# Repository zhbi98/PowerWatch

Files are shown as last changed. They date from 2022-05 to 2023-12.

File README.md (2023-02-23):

# PowerWatch 迷你 USB 电源功率计

## 1. 项目简介

PowerWatch 是我设计的一个 Mini-USB 电源功率计，设计包含外观结构，电路 PCB，程序固件。

PowerWatch 在硬件设计上支持同时采样被测电源的电压，电流及功率等参数，同时通过软件的形式实现了电能实时监测功能。

电能实时监测功能可以方便的知道被监测电源所输出的电能。 比如通过 PowerWatch 可以知道充电宝为手机充电时，充电宝流入手机的电能为多少 mAh。

而其中 mAh 表明的是电能单位，例如以 $x$ mA 电流持续输出 $1$ h 时间，则输出的电能为 $x$ mAh。

## 2. 硬件介绍

**(1)** 微控制器：采用国产兆易 GD32F103RCT6，芯片主频 96MHz 最高可达 108MHz，64P 引脚，RAM 空间 64KB，ROM 空间 256KB，支持 USB 通信。

**(2)** 屏幕：驱动芯片 ST7789V3，材质 IPS，采用 8 位并行 8080 通信接口，分辨率 320x170。

**(3)** Flash 芯片：GD25Q64 64MBit 即 8MByte。

**(4)** 电压电流采样芯片：采用德州仪器 TI 的 INA226AIDGSR 芯片。 

**(5)** 外壳模型：3D 打印，材料使用尼龙或工程塑料 。

## 3. 目录说明

### 3.1 Firmware 目录

该目录包含 PowerWatch 的所有功能源码实现，芯片驱动库，以及 Keil 编译工程所在目录，现在来简单介绍一下。

`mdk5/` 目录即为 MDK-ARM（即 Keil5 集成开发环境） 的工程文件。

`test/` 目录包含所有功能实现源码，以及需要用到的芯片驱动库，图形界面库 LVGL。

程序主要包含以下内容：

**(1)** GD32f103 的 USB Device 设备驱动，USB 驱动使用的设备描述符是 CDC 虚拟串口，使用 USB 接口可以用于和上位机进行数据通讯。

**(2)** ST7789V3 屏幕芯片驱动。

**(3)** 电压电流采样芯片驱动。

**(4)** 移植好的 LVGL8.2.0 的 UI 绘图库，这个 UI 库可以实现美观的图形界面，使用 LVGL 后就不需要我们自己控制屏幕逐像素的绘制图形来实现 UI 了。

注意：如果需要编译此工程需要安装 keil5 集成开发环境，以及在 keil5 中安装 GD32F10 系列的芯片描述包, 安装好后点击本项目工程文件夹下的工程文件启动 keil 直接编译即可。

GD32F10 芯片描述包可以到兆易官方网站下载，找到 **GD32F1x0 AddOn** 压缩包，芯片描述包就在该压缩包下，下载地址：[点击这里](https://www.gd32mcu.com/cn/download/7?kw=GD32F1)。

---

power_watch_firmware_v1.0.hex：为 PowerWatch 源码的编译后的固件，如果使用编译固件，需要使芯片进入 BOOT 模式，并使用 PCB 板上预留的串口来写入该固件。

### 3.2 Hardware 目录

PowerWatch 的 PCB 工程源文件，该文件夹下包含电路原理图，以及 PCB 制造文件（即 Gerber 文件），器件 BOM 单（用于 SMT 贴片），器件位置文件（用于 SMT 贴片）。

将 Gerber 文件压缩后到嘉立创网站下单即可将 PCB 打样出来，BOM 单和器件位置文件是嘉立创格式，PCB 打样后可以自行按照 BOM 单购买元器件手工焊接，或利用我提供的 BOM 单和器件坐标文件运用嘉立创的 SMT 贴片服务来贴片。

硬件 PCB 已经打样验证通过，想制作的小伙伴可以放心打样使用。

---

PCB 设计时原本的设想是使用 **STM32F103RCT6** 这颗芯片作为微控制器使用的，但是奈何 **STM32F103RCT6** 价格较高，所以最终芯片使用的是国产兆易的 **GD32F103RCT6** 系列芯片。

但是这对电路并不影响，因为 **GD32F103RCT6** 可以不需要任何改动而实现 PIN 对 PIN 的引脚以及外设兼容 **STM32F103RCT6** 芯片（即它们的每一根引脚和外设的功能是相同的）。

### 3.3 Image 目录

该目录是功率计制作实物效果图片展示，观看制作效果可以查看该目录下的实物照片。

### 3.4 Structure 目录

该目录存放功率计外壳模型文件 `.step` 格式，外壳模型包含壳体，按键帽，屏幕支架，上盖板，直接下载用于 3D 打印即可。

为了美观考虑盖板最好使用透明亚克力板进行制作，普通 3D 打印无法实现透明。

**(1)** 壳体 box_v2.0.step 建议采用黑色尼龙材材料 3D 打印。

**(2)** 屏幕支架 bracket_v2.0.step 建议采用透明树脂材料 3D 打印。

**(3)** 上盖板 panel_v2.0.step 建议采用亚克力或聚碳酸酯材料 CNC 加工。

**(4)** 按键帽 button1_v2.0.step，button2_v2.0.step，button3_v2.0.step，button4_v2.0.step 建议采用尼龙材料 3D 打印。

### 3.5 Docs 目录

用到的芯片配套的数据手册。

## 4. 外观设计

**最初的 V1.0 版本模型效果**

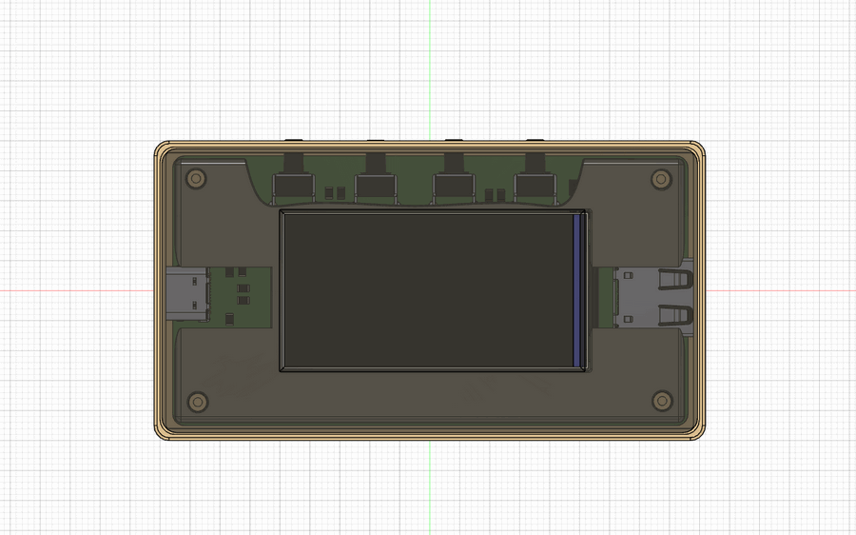
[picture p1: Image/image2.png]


**改进后 V2.0 版本模型效果**

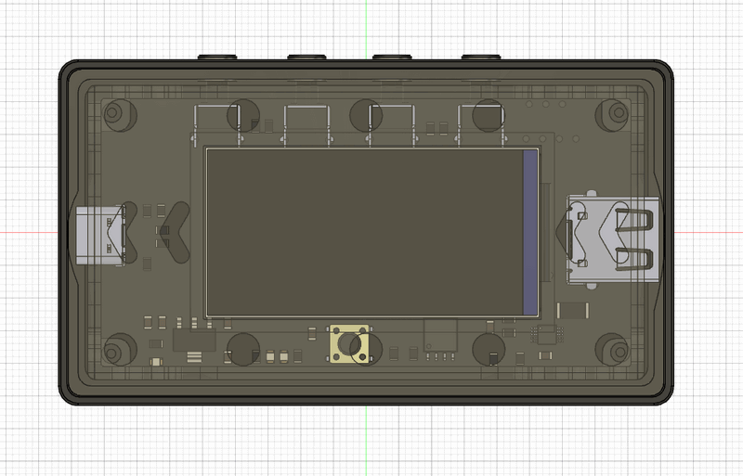
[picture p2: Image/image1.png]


## 5. 实物展示

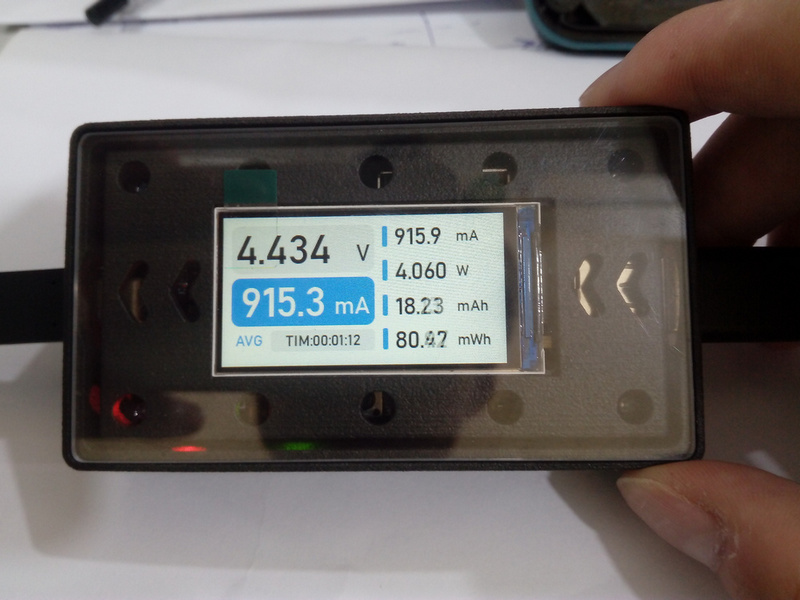
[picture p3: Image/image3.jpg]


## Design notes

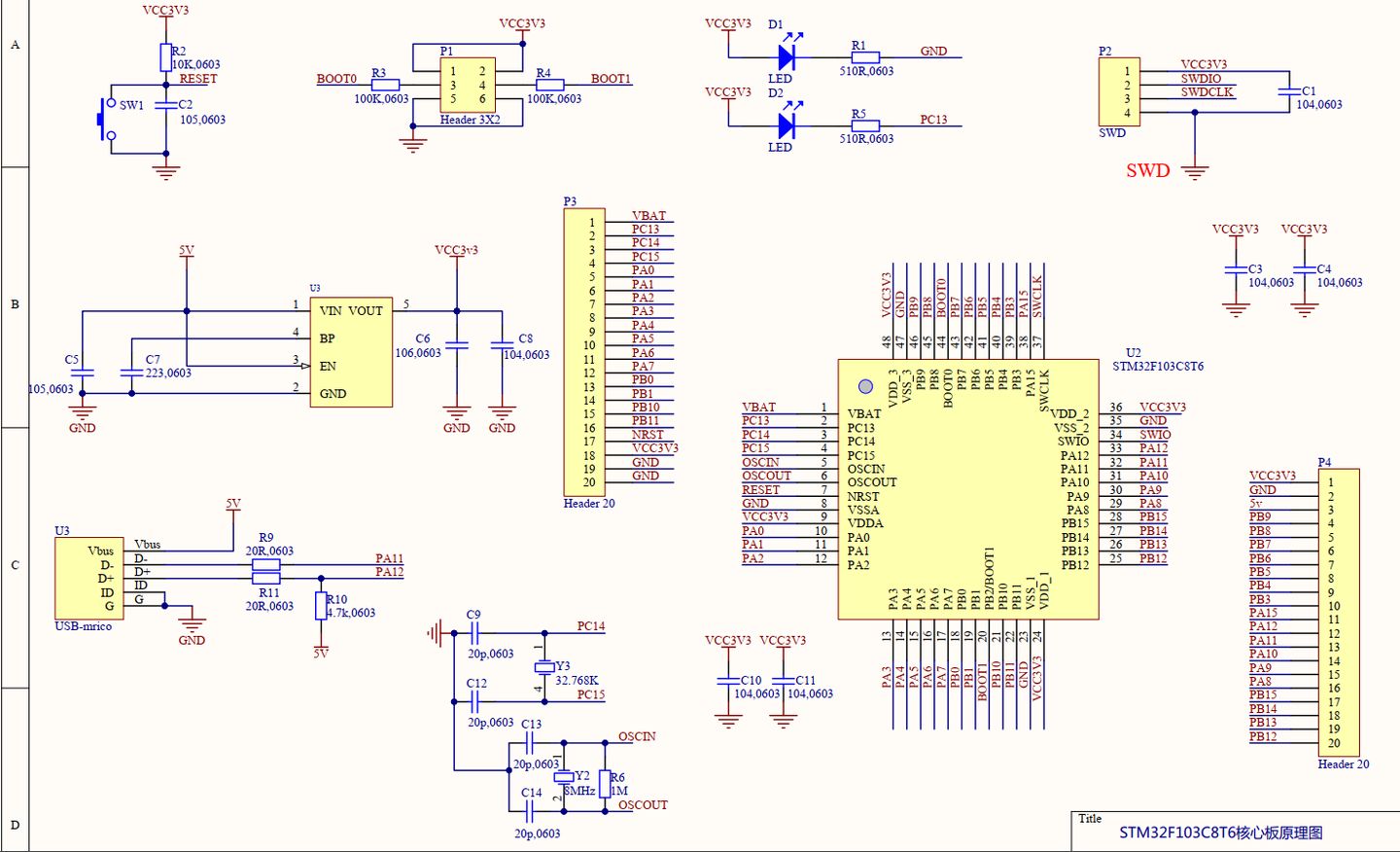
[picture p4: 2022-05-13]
Docs/STM32.jpg

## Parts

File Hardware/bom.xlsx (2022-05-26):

Comment型号 | Designator位号 | Footprint封装
22pF | C1,C4 | 0805
10uF | C2,C5 | 0805
0.1uF | C3,C6,C7,C8,C9,C10,C11,C12,C13 | 0805
17-21/R6C-AQ2R2B/3T | D1 | 0805
17-21SYGC/S530-E3/TR8 | D2 | 0805
17-21SYGC/S530-E3/TR8 | D3 | 0805
TYPE-C-31-M-12 | J3 | USB4105-GF-A
KH-FG0.5-H2.0-30PIN | J4 | Hirose_FH12-30S-0.5SH_1x30-1MP_P0.50mm_Horizontal
903-241B1011D10100 | J6 | USB1130-15-A_REVA
MMBT3906 | Q1 | SOT-23
220R | R1,R2,R3,R4,R14 | 0805
10M | R5 | 0805
10K | R6,R10,R22,R24 | 0805
0.5K | R7,R8 | 0805
1k | R9 | 0805
20R | R11, R12 | 0805
1K | R13 | 0805
100mR | R15 | 2010
5.1K | R16,R17,R18,R19,R20,R21 | 0805
100R | R23 | 0805
1-1825027-1 | S1,S2,S3,S4 | B3F-3100
1825910-6 | SW1 | B3F-1000
LM1117 | U1 | SOT-223
GD32F103RCT6 | U2 | LQFP-64_10x10mm_P0.5mm
INA226 | U3 | SOP50P490X110-10N
W25Q32JVSS | U4 | SOIC127P790X216-8N
49MD-8.00-20-10-10/A | Y1 | 49SMD

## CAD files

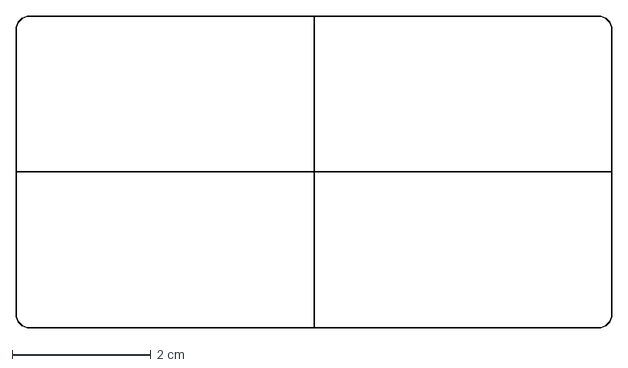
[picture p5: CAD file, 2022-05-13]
Hardware/edge_cuts.dxf
8.60 x 4.50 cm

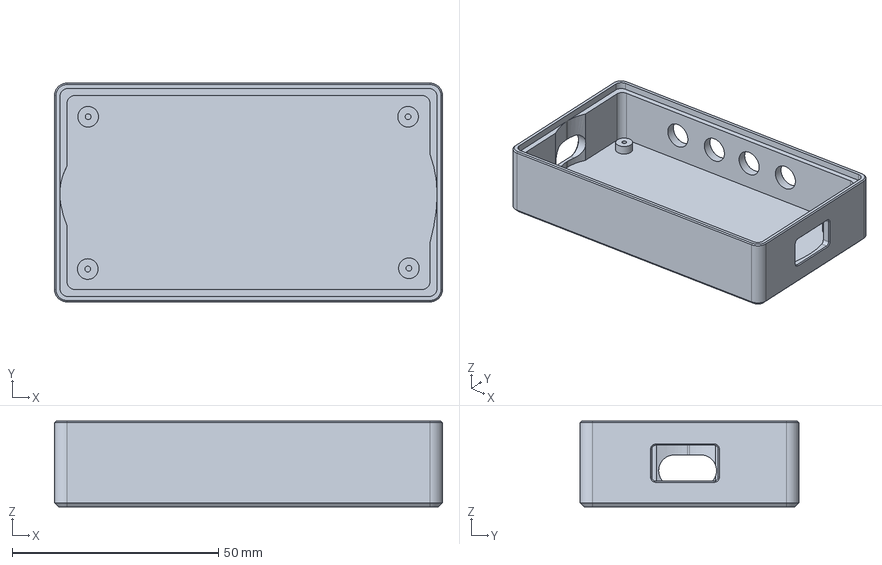
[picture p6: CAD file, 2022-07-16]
Structure/box_v2.0.step
94.0 x 53.0 x 20.8 mm

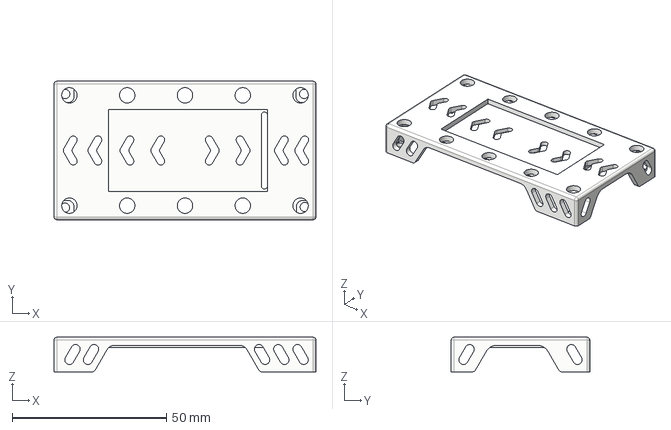
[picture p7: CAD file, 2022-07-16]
Structure/bracket_v2.0.step
85.0 x 45.0 x 11.3 mm

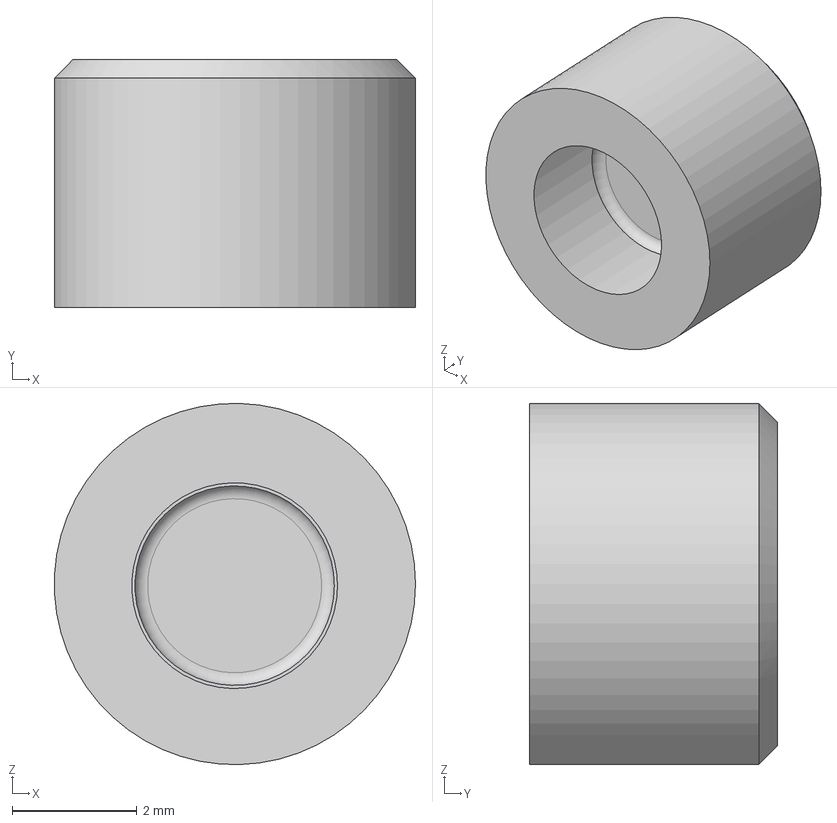
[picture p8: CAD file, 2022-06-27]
Structure/button2_v2.0.step
5.80 x 3.98 x 5.80 mm

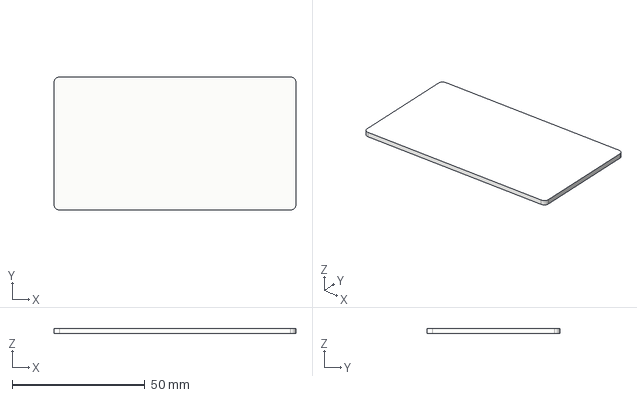
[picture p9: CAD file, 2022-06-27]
Structure/panel_v2.0.step
91.0 x 50.0 x 2.00 mm

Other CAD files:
Structure/button4_v2.0.step
Structure/button3_v2.0.step
Structure/button1_v2.0.step

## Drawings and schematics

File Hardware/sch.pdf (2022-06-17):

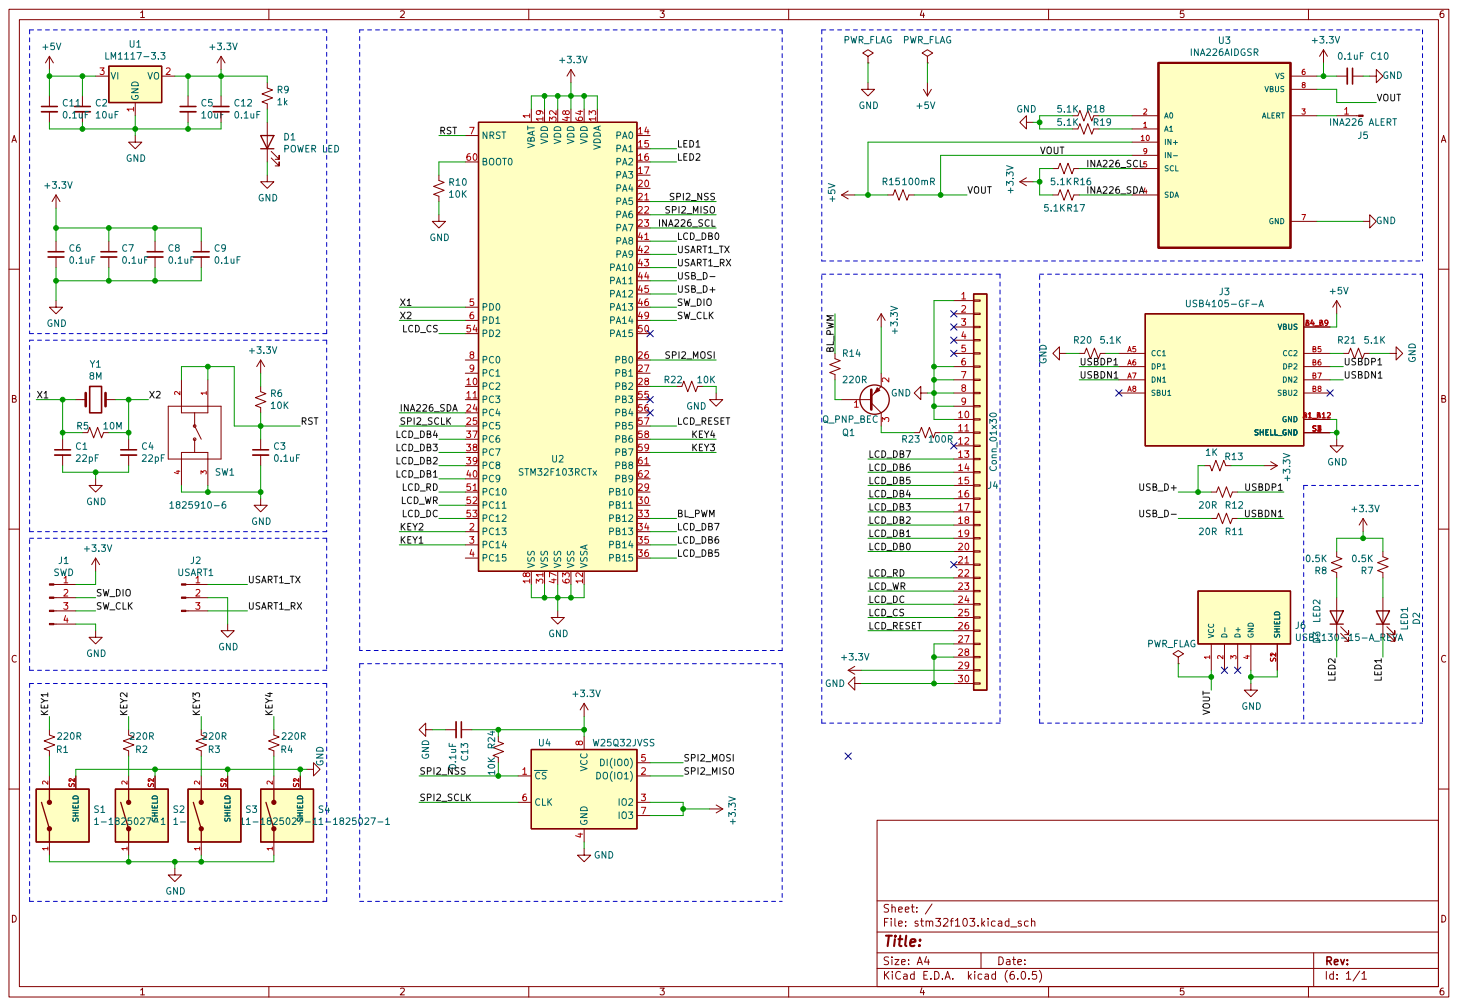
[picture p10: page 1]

1 PC2 10 PC3 11 VSSA 12 VDDA 13 PA0 14 PA1 15 PA2 16 PA3 17 VSS 18 VDD 19 PC13 2 PA4 20 PA5 21 PA6 22 PA7 23 PC4 24 PC5 25 PB0 26 PB1 27 PB2 28 PB10 29 PC14 3 PB11 30 VSS 31 VDD 32 PB12 33 PB13 34 PB14 35 PB15 36 PC6 37 PC7 38 PC8 39 PC15 4 PC9 40 PA8 41 PA9 42 PA10 43 PA11 44 PA12 45 PA13 46 VSS 47 VDD 48 PA14 49 PD0 5 PA15 50 PC10 51 PC11 52 PC12 53 PD2 54 PB3 55 PB4 56 PB5 57 PB6 58 PB7 59 PD1 6 BOOT0 60 PB8 61 PB9 62 VSS 63 VDD 64 NRST 7 PC0 8 PC1 9 U2 STM32F103RCTx R22 10K GND

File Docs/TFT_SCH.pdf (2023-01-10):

# 中景园电子1.9寸IPS LCD显示屏模块原理图

# 分辩率：170x320

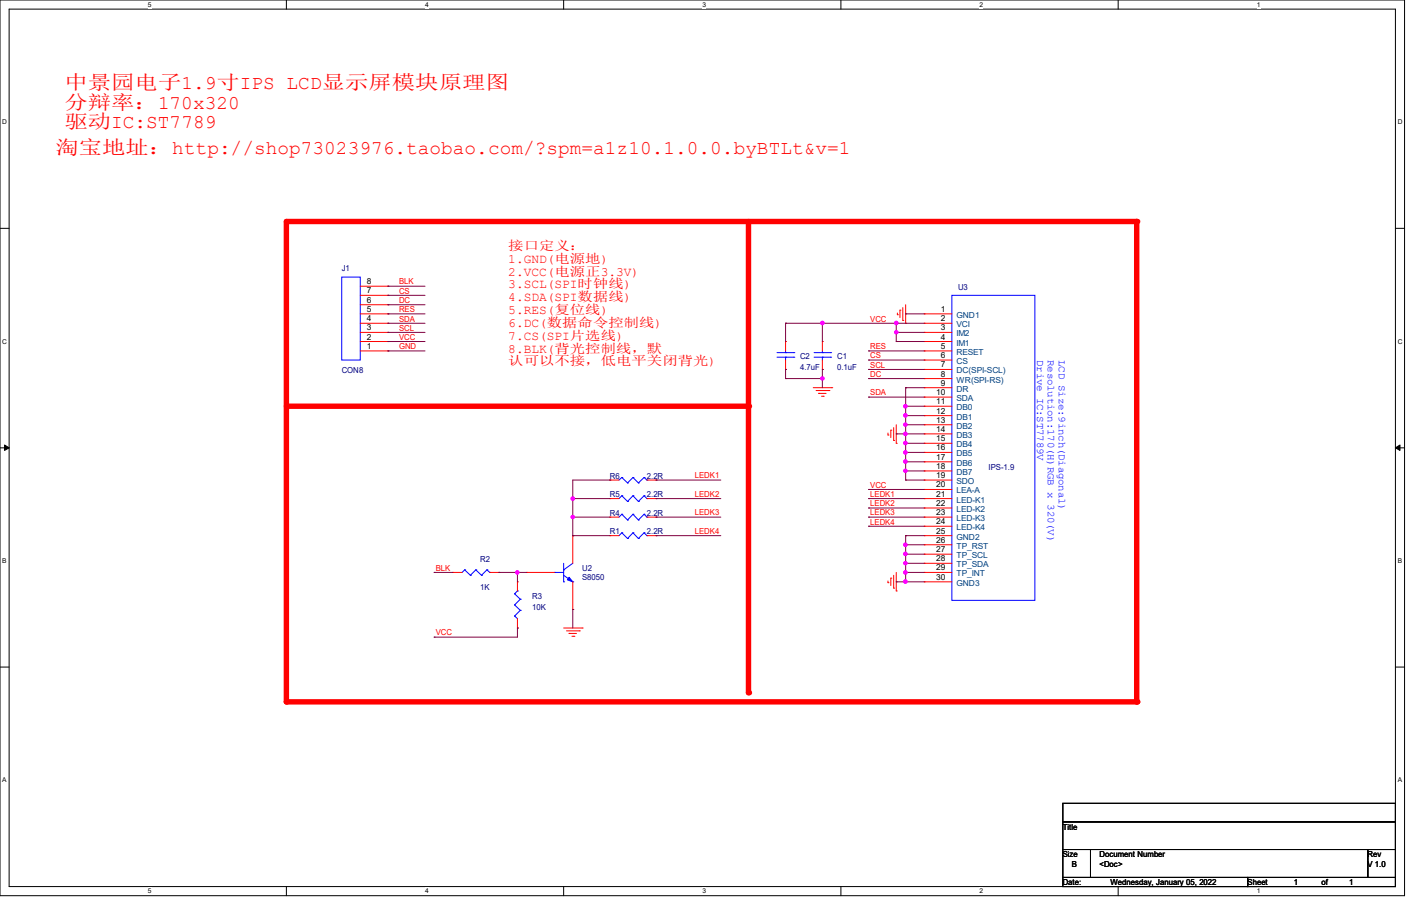
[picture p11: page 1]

驱动IC:ST7789
淘宝地址：http://shop73023976.taobao.com/?spm=a1z10.1.0.0.byBTLt&v=1

接口定义：
1.GND(电源地)
2.VCC(电源正3.3V)
3.SCL(SPI时钟线) 4.SDA(SPI数据线)

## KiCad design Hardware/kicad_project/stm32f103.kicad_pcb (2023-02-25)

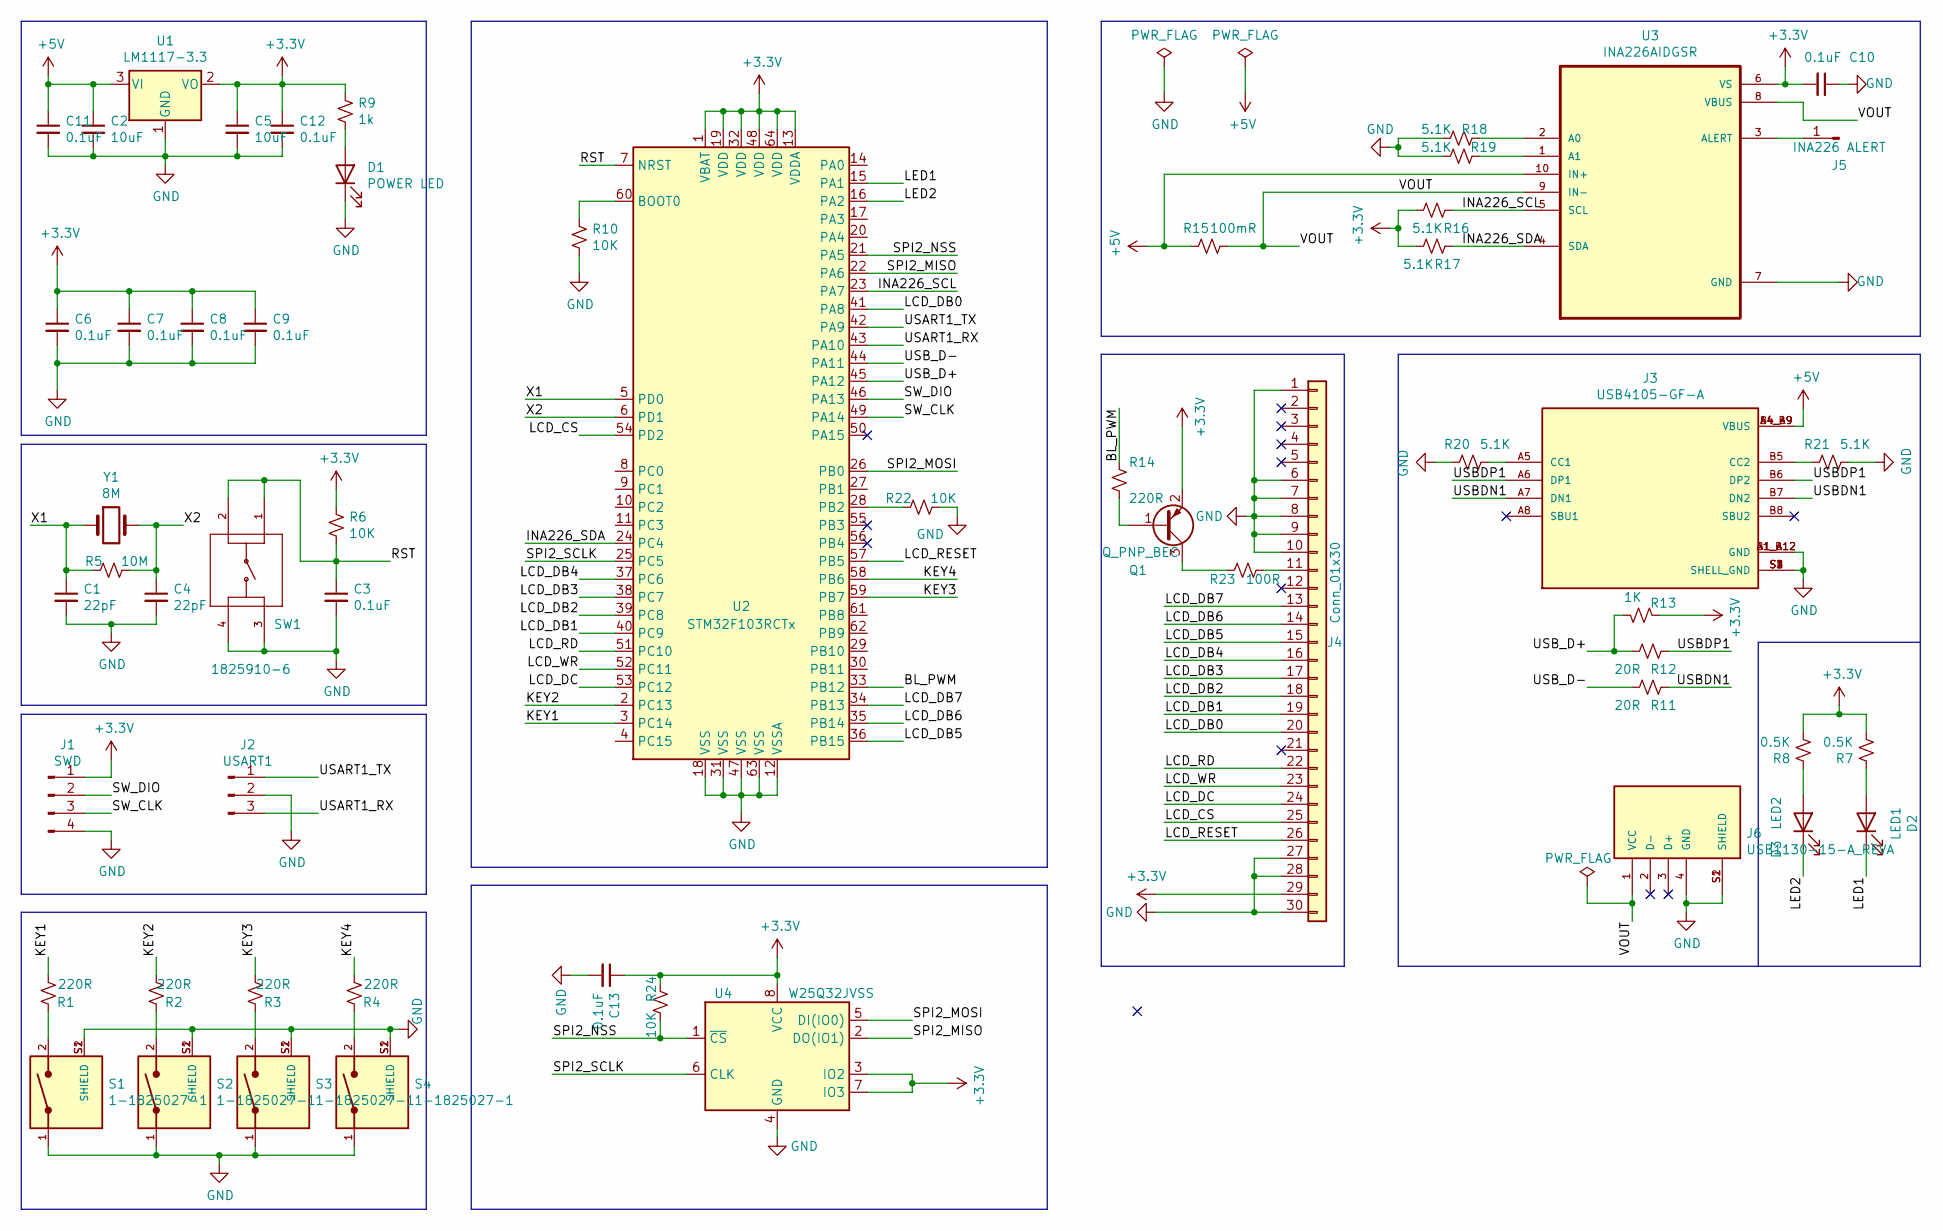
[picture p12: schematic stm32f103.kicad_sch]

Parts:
C1, C4: 22pF; C_0805_2012Metric
C2, C5: 10uF; C_0805_2012Metric
C3, C6, C7, C8, C9, C10, C11, C12, C13: 0.1uF; C_0805_2012Metric
D1: POWER LED; LED_0805_2012Metric
D2: LED1; LED_0805_2012Metric
D3: LED2; LED_0805_2012Metric
J1: SWD; PinSocket_1x04_P2.54mm_Vertical
J2: USART1; PinSocket_1x03_P2.54mm_Vertical
J3: USB4105-GF-A; USB-C-SMD_16P_USB4105-GF-A; PARTREV A3
J4: Conn_01x30; Hirose_FH12-30S-0.5SH_1x30-1MP_P0.50mm_Horizontal
J5: INA226 ALERT; PinSocket_1x01_P2.54mm_Vertical
J6: USB1130-15-A_REVA; USB-A-TH_4P_USB1130-15-A-REVA; PARTREV A
Q1: Q_PNP_BEC; SOT-23
R1, R2, R3, R4, R14: 220R; R_0805_2012Metric
R5: 10M; R_0805_2012Metric
R6, R10, R22, R24: 10K; R_0805_2012Metric
R7, R8: 0.5K; R_0805_2012Metric
R9: 1k; R_0805_2012Metric
R11, R12: 20R; R_0805_2012Metric
R13: 1K; R_0805_2012Metric
R15: 100mR; R_2010_5025Metric
R16, R17, R18, R19, R20, R21: 5.1K; R_0805_2012Metric
R23: 100R; R_0805_2012Metric
S1, S2, S3, S4: 1-1825027-1; KEY-TH_L6.0-W6.0-H_B3F-3100
SW1: 1825910-6; KEY-TH_L6.0-W6.0-V_B3F-1000
U1: LM1117-3.3; SOT-223
U2: STM32F103RCTx; LQFP-64_10x10mm_P0.5mm
U3: INA226AIDGSR; VSSOP-10_L2.9-W5.05-P0.5_INA226AIDGSR
U4: W25Q32JVSS; SOIC-8_L4.8-W5.8-P1.27_W25Q32JVSS
Y1: 8M; Crystal_SMD_HC49-SD

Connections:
+3V3: C5.1, C6.1, C7.1, C8.1, C9.1, C10.2, C12.1, C13.1, J1.1, J4.29, Q1.2 (E), R6.1, R7.2, R8.2, R9.1, R13.1, R16.1, R17.1, R24.2, U1.2 (VO), U2.1 (VBAT), U2.13 (VDDA), U2.19 (VDD), U2.32 (VDD), U2.48 (VDD), U2.64 (VDD), U3.6 (VS), U4.3 (IO2), U4.7 (IO3), U4.8 (VCC)
+5V: C2.1, C11.1, J3.A4_B9 (VBUS), J3.B4_A9 (VBUS), R15.2, U1.3 (VI), U3.10 (IN+)
/BL_PWM: R14.1, U2.33 (PB12)
/INA226_SCL: R16.2, U2.23 (PA7), U3.5 (SCL)
/INA226_SDA: R17.2, U2.24 (PC4), U3.4 (SDA)
/KEY1: R1.2, U2.3 (PC14)
/KEY2: R2.2, U2.2 (PC13)
/KEY3: R3.2, U2.59 (PB7)
/KEY4: R4.2, U2.58 (PB6)
/LCD_CS: J4.25, U2.54 (PD2)
/LCD_DB0: J4.20, U2.41 (PA8)
/LCD_DB1: J4.19, U2.40 (PC9)
/LCD_DB2: J4.18, U2.39 (PC8)
/LCD_DB3: J4.17, U2.38 (PC7)
/LCD_DB4: J4.16, U2.37 (PC6)
/LCD_DB5: J4.15, U2.36 (PB15)
/LCD_DB6: J4.14, U2.35 (PB14)
/LCD_DB7: J4.13, U2.34 (PB13)
/LCD_DC: J4.24, U2.53 (PC12)
/LCD_RD: J4.22, U2.51 (PC10)
/LCD_RESET: J4.26, U2.57 (PB5)
/LCD_WR: J4.23, U2.52 (PC11)
/LED1: D2.1 (K), U2.15 (PA1)
/LED2: D3.1 (K), U2.16 (PA2)
/RST: C3.1, R6.2, SW1.1, SW1.2, U2.7 (NRST)
/SPI2_MISO: U2.22 (PA6), U4.2 (DO(IO1))
/SPI2_MOSI: U2.26 (PB0), U4.5 (DI(IO0))
/SPI2_NSS: R24.1, U2.21 (PA5), U4.1 (~CS)
/SPI2_SCLK: U2.25 (PC5), U4.6 (CLK)
/SW_CLK: J1.3, U2.49 (PA14)
/SW_DIO: J1.2, U2.46 (PA13)
/USART1_RX: J2.3, U2.43 (PA10)
/USART1_TX: J2.1, U2.42 (PA9)
/USBDN1: J3.A7 (DN1), J3.B7 (DN2), R11.2
/USBDP1: J3.A6 (DP1), J3.B6 (DP2), R12.2
/USB_D+: R12.1, R13.2, U2.45 (PA12)
/USB_D-: R11.1, U2.44 (PA11)
/VOUT: J6.1 (VCC), R15.1, U3.8 (VBUS), U3.9 (IN-)
/X1: C1.1, R5.2, U2.5 (PD0), Y1.1
/X2: C4.1, R5.1, U2.6 (PD1), Y1.2
GND: C1.2, C2.2, C3.2, C4.2, C5.2, C6.2, C7.2, C8.2, C9.2, C10.1, C11.2, C12.2, C13.2, D1.1 (K), J1.4, J2.2, J3.A1_B12 (GND), J3.B1_A12 (GND), J3.S1 (SHELL_GND), J3.S2 (SHELL_GND), J3.S3 (SHELL_GND), J3.S4 (SHELL_GND), J4.1, J4.6, J4.7, J4.8, J4.9, J4.10, J4.27, J4.28, J4.30, J6.4 (GND), J6.S1 (SHIELD), J6.S2 (SHIELD), R10.2, R18.1, R19.1, R20.2, R21.1, R22.2, S1.1, S1.S1 (SHIELD), S1.S2 (SHIELD), S2.1, S2.S1 (SHIELD), S2.S2 (SHIELD), S3.1, S3.S1 (SHIELD), S3.S2 (SHIELD), S4.1, S4.S1 (SHIELD), S4.S2 (SHIELD), SW1.3, SW1.4, U1.1 (GND), U2.12 (VSSA), U2.18 (VSS), U2.31 (VSS), U2.47 (VSS), U2.63 (VSS), U3.7 (GND), U4.4 (GND)
unnamed: D1.2 (A), R9.2
unnamed: D2.2 (A), R7.1
unnamed: D3.2 (A), R8.1
unnamed: J3.A5 (CC1), R20.1
unnamed: J3.B5 (CC2), R21.2
unnamed: J4.11, R23.2
unnamed: J5.1, U3.3 (ALERT)
unnamed: Q1.1 (B), R14.2
unnamed: Q1.3 (C), R23.1
unnamed: R1.1, S1.2
unnamed: R2.1, S2.2
unnamed: R3.1, S3.2
unnamed: R4.1, S4.2
unnamed: R10.1, U2.60 (BOOT0)
unnamed: R18.2, U3.2 (A0)
unnamed: R19.2, U3.1 (A1)
unnamed: R22.1, U2.28 (PB2)

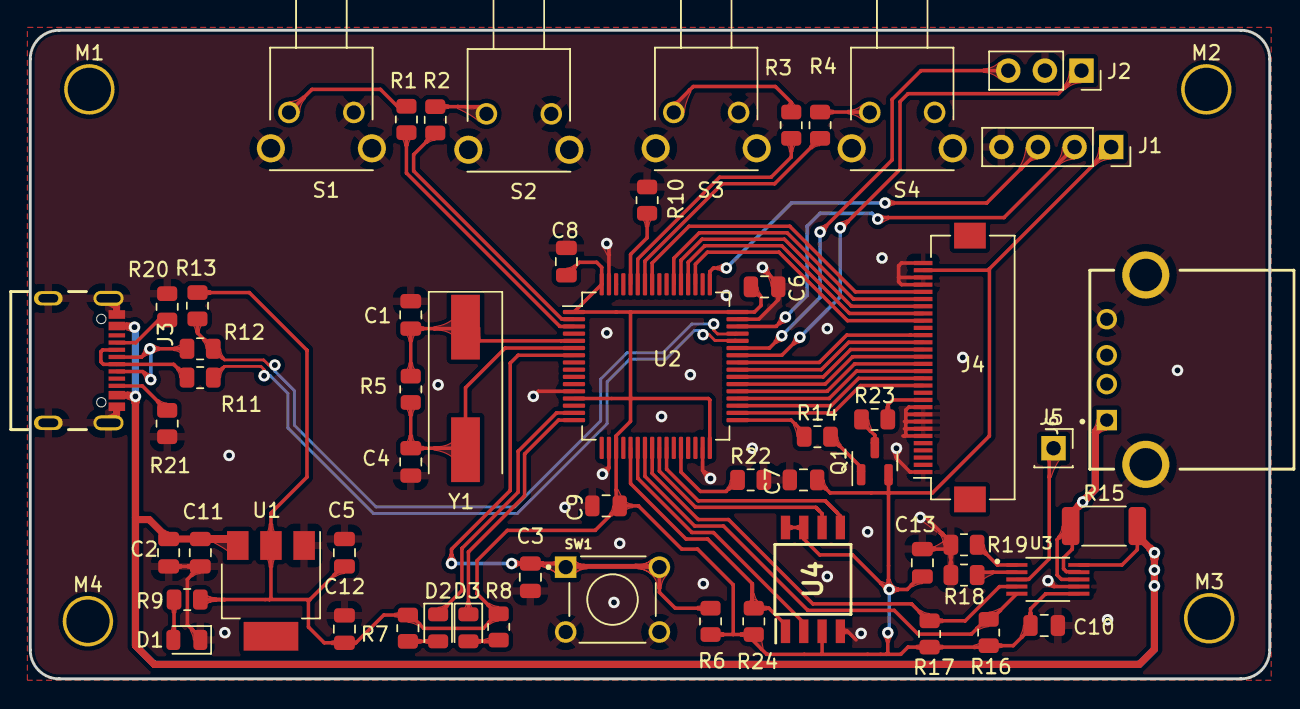
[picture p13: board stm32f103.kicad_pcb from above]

Board: 2 copper layers, 86.0 x 45.0 mm, 61 parts (0 on the bottom side), 58 nets.

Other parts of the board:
M1, M2, M3, M4: Mounting_Holes_3mm_THT

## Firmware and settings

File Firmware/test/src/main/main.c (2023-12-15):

/**
 * @file main.c
 *
 */

/*********************
 *      INCLUDES
 *********************/

#include "gd32f10x.h"

#include <stdint.h>
#include "led.h"
#include "key.h"
#include "time.h"
#include "log.h"
#include "usbd_cdc.h"
#include "st7789.h"
#include "ina226.h"
#include "gd25q64.h"
#include "temp.h"
#include "ina226.h"
#include "kalman.h"

#include "lvgl.h"
#include "nt_pm.h"
#include "nt_minitask.h"

#include "qflow.h"
#include "blight.h"

#include "dialplateview.h"
#include "dialplate.h"
#include "infosview.h"
#include "infos.h"
#include "recentview.h"
#include "recent.h"

#include "resource.h"

/**********************
 * GLOBAL FUNCTIONS
 **********************/

/**
  * 说明 : 初始化内核时钟(108M)
  * 参数 : 无
  * 返回 : 无
  */ 
void sys_clock_config(void)
{
    /** 使能外部晶振 */
    rcu_osci_on(RCU_HXTAL);
    /** 等待晶振稳定 */
    while (rcu_osci_stab_wait(RCU_HXTAL) != SUCCESS);

    /** 设置PREDV0 */
    rcu_predv0_config(RCU_PREDV0_DIV1);
    /** PLL设置 */
    rcu_pll_config(RCU_PLLSRC_HXTAL, RCU_PLL_MUL9);
    /** 使能PLL */
    rcu_osci_on(RCU_PLL_CK);
    /** 等待PLL稳定 */
    while (rcu_osci_stab_wait(RCU_HXTAL) != SUCCESS);

    /** 总线时钟配置 */
    rcu_ahb_clock_config(RCU_AHB_CKSYS_DIV1);
    rcu_apb1_clock_config(RCU_APB1_CKAHB_DIV2);
    rcu_apb2_clock_config(RCU_APB2_CKAHB_DIV1); 
    /** 系统时钟源选择 */
    rcu_system_clock_source_config(RCU_CKSYSSRC_PLL);
    while(rcu_system_clock_source_get() != RCU_SCSS_PLL);

    /** 更新SystemCoreClock全局变量 */
    SystemCoreClockUpdate();
}

/*
-----------------------------------------
    Timing 0.1s

    Prescaler = AHB Clock / Timing Clock
              = 84(MHz) / 50(KHz)
              = 84000000(hz) / 50000(hz)
              = 1680

    T = 1 / f
      = 1(s) / f(Hz)
      = 1000000(us) / 50000(hz)
      = 20(us/times)

    Period = Timing / T
           = 0.1(s) / 20(us/times)
           = 100000(us) / 20(us/times)
           = 5000(times)

-----------------------------------------
    Timing 0.5s
    
    Prescaler = AHB Clock / Timing Clock
              = 84(MHz) / 10(KHz)
              = 84000000(hz) / 10000(hz)
              = 8400

    T = 1 / f
      = 1(s) / f(Hz)
      = 1000000(us) / 10000(hz)
      = 100(us/times)

    Period = Timing / T
           = 0.5(s) / 100(us/times)
           = 500000(us) / 100(us/times)
           = 5000(times)
-----------------------------------------
*/

void _timer_init(uint32_t _prescaler, uint32_t _period)
{
    /**
     * TIMER configuration: generate PWM signals
     * with different duty cycles:
     * TIMERCLK = SystemCoreClock / 120 = 1MHz
     */
    timer_oc_parameter_struct timer_out_init;
    timer_parameter_struct time_init;

    rcu_periph_clock_enable(RCU_TIMER1);
    timer_deinit(TIMER1);

    time_init.prescaler         = _prescaler - 1;
    time_init.alignedmode       = TIMER_COUNTER_EDGE;
    time_init.counterdirection  = TIMER_COUNTER_UP;
    time_init.period            = _period;
    time_init.clockdivision     = TIMER_CKDIV_DIV1;
    time_init.repetitioncounter = 0;
    timer_init(TIMER1, &time_init);

#if 0
    CH0 config in pwm mode
    timer_out_init.outputstate  = TIMER_CCX_ENABLE;
    timer_out_init.outputnstate = TIMER_CCXN_DISABLE;
    timer_out_init.ocpolarity   = TIMER_OC_POLARITY_HIGH;
    timer_out_init.ocnpolarity  = TIMER_OCN_POLARITY_HIGH;
    timer_out_init.ocidlestate  = TIMER_OC_IDLE_STATE_LOW;
    timer_out_init.ocnidlestate = TIMER_OCN_IDLE_STATE_LOW;
    timer_channel_output_config(TIMER1,
        SUART_TIMER_CH, &timer_out_init);

    timer_channel_output_pulse_value_config(
        TIMER1, SUART_TIMER_CH, 250);
    timer_channel_output_mode_config(
        TIMER1, SUART_TIMER_CH, TIMER_OC_MODE_PWM0);
    timer_channel_output_shadow_config(
        TIMER1, SUART_TIMER_CH, TIMER_OC_SHADOW_DISABLE);
    timer_primary_output_config(TIMER1, ENABLE);
    timer_auto_reload_shadow_enable(TIMER1);
#endif

    nvic_irq_enable(TIMER1_IRQn, 1, 1);
    timer_interrupt_enable(TIMER1, TIMER_INT_UP);
    timer_enable(TIMER1);
}

void TIMER1_IRQHandler()
{
    if (timer_interrupt_flag_get(TIMER1, TIMER_INT_FLAG_UP) == SET) {
        timer_interrupt_flag_clear(TIMER1, TIMER_INT_FLAG_UP);
        lv_tick_inc(1);
        nt_task_tick_inc(1);

        QFLOW_TICK_INC(1);
        QFLOW_TAKE(
            ina226_filte_get_cur(), 
            ina226_filte_get_pow());
        qflow_work();
    }
}

void ina226_update()
{
    ina226_filte_work();
    qflow_dura_work();
}

void key_update()
{
    switch (key_read_event()) {
    case KEY1_EVT:
        lcd_light_state_reset();
        break;
    case KEY2_EVT:
        lcd_light_state_reset();
        break;
    case KEY3_EVT:
        lcd_light_state_reset();
        break;
    case KEY4_EVT:
        lcd_light_state_repeat();
        break;
    }
    lcd_light_state_work();
    led_light_work(&led1);
    led_light_work(&led2);
    avg_filte_work();
}

extern lv_indev_t * indev_keypad;

int main()
{
    /*SystemInit()->system_clock_config()->system_clock_108m_hxtal();*/
    sys_clock_config();
    _timer_init(960, 100); /*Timer tick 1ms*/
    led_gpio_init();
    key_gpio_init();
    usart_init();
    usb_cdc_init();
    st7789_init();
    INA226_Init();
    inside_temp_adc_init();
    gd25q64_spi_gpio_init();

    lv_init();
    lv_port_disp_init();
    lv_port_indev_init();

    lv_group_t * group = lv_group_create();
    lv_indev_set_group(indev_keypad, group);
    lv_group_set_default(group);

    /** 定义一个活动屏幕, 否则 `lv_disp_set_bg_color` 屏幕背景颜色设置无效 */
    lv_obj_t * scr = lv_scr_act();
    lv_obj_remove_style_all(scr);
    lv_obj_clear_flag(scr, LV_OBJ_FLAG_SCROLLABLE);
    lv_disp_set_bg_color(
        lv_disp_get_default(), 
        lv_color_white()
        /*lv_color_black()*/
    );

    _nt_resource_init();

    _nt_view_pointer_init(&dialplateview);
    _nt_view_pointer_init(&recentview);
    _nt_view_pointer_init(&infosview);
    _NT_START_PAGE(dialplateview);

    nt_task_add(ina226_update, 50, 50);
    nt_task_add(key_update, 100, 100);

    for (;;) {
        lv_task_handler();
        nt_task_handler();
    }

    return 0;
}

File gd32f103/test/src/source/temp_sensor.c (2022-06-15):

#include "temp_sensor.h"

void temp_adc_rcu_config()
{
    /* enable ADC clock */
    rcu_periph_clock_enable(ADC_CLOCK);
    /* config ADC clock */
    rcu_adc_clock_config(RCU_CKADC_CKAPB2_DIV12);
}

/*!
    \brief      configure the ADC peripheral
    \param[in]  none
    \param[out] none
    \retval     none
*/
void temp_adc_config()
{
    temp_adc_rcu_config();

    /* ADC SCAN function enable */
    adc_special_function_config(/*ADC0*/CURRENT_ADC, ADC_SCAN_MODE,ENABLE);  
    /* ADC trigger config */
    adc_external_trigger_source_config(/*ADC0*/CURRENT_ADC, ADC_INSERTED_CHANNEL, ADC0_1_2_EXTTRIG_INSERTED_NONE);
    /* ADC data alignment config */
    adc_data_alignment_config(/*ADC0*/CURRENT_ADC, ADC_DATAALIGN_RIGHT);
    /* ADC mode config */
    adc_mode_config(ADC_MODE_FREE);  
    /* ADC channel length config */
    adc_channel_length_config(/*ADC0*/CURRENT_ADC, ADC_INSERTED_CHANNEL, 2);

    /* ADC temperature sensor channel config */
    adc_inserted_channel_config(/*ADC0*/CURRENT_ADC, 0, ADC_CHANNEL_16, ADC_SAMPLETIME_239POINT5);
    /* ADC internal reference voltage channel config */
    adc_inserted_channel_config(/*ADC0*/CURRENT_ADC, 1, ADC_CHANNEL_17, ADC_SAMPLETIME_239POINT5);

    /* ADC external trigger enable */
    adc_external_trigger_config(/*ADC0*/CURRENT_ADC, ADC_INSERTED_CHANNEL,ENABLE);

    /* ADC temperature and Vrefint enable */
    adc_tempsensor_vrefint_enable();
    
    /* enable ADC interface */
    adc_enable(/*ADC0*/CURRENT_ADC);
    sleep_ms(5);    
    /* ADC calibration and reset calibration */
    adc_calibration_enable(/*ADC0*/CURRENT_ADC);
}

int read_temp()
{
#if 1 // GD32F103 TEMP SENSOR TEST
		float temperature = 0.0;
		float vref_value = 0.0;

        adc_software_trigger_enable(CURRENT_ADC, ADC_INSERTED_CHANNEL);
        sleep_ms(100);

        temperature = (1.43 - ADC_IDATA0(CURRENT_ADC)*3.3/4096) * 1000 / 4.3 + 25;
        vref_value = (ADC_IDATA1(CURRENT_ADC) * 3.3 / 4096);

        // usb_fs_send_fmt_string("Temp: %2.0f\n", temperature);
        // sleep_ms(100);
        // usb_fs_send_fmt_string("Vref: %5.3fV\n", vref_value);
        // sleep_ms(500);
        return (int)temperature;
#endif
}

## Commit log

2022-05-14 ina226 fix current and power CAL value
    [ina226.c, ina226.h]
2022-05-26 fix pcb router
    [USB-POWER v14.dxf, elecal_bom.xlsx, elecal_edge_cuts.dxf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]
2022-05-28 Add ips screen lcd driver
2022-05-28 Fix screen direction describe
    [st7789.c]
2022-05-28 Add gd25q64 flash driver
2022-05-30 Fix st7789v3 video memory coordinate calculation bug
    [st7789.c]
2022-05-30 Modify display driver API
2022-05-31 Add gd32f103 temp sensor
2022-06-01 Add button driver
2022-06-01 LVGL connect key driver
2022-06-05 Fix sampling resistor
2022-06-14 Add 3D model
    [elecal_box.stl, elecal_bracket.stl, elecal_panel.stl]
2022-06-15 Modify power measure
2022-06-17 Add Elecal schematic
2022-06-18 Support main display switching
2022-06-23 Modify ina226 driver, display handler
2022-06-27 Update 3D models, usb cdc
    [elecal_box_v1.0.stl, elecal_box_v2.0.step, elecal_box_v2.0.stl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]
2022-07-16 Add firmware
    [elecal_box_v2.0.step, elecal_bracket_v2.0.step]
2023-01-04 修改 PCB 工程
    [elecal_bom.xlsx, elecal_edge_cuts.dxf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]
2023-01-04 修改目录
    [elecal_box_v1.0.stl, elecal_box_v2.0.step, elecal_bracket_v1.0.stl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]
2023-01-04 更新 PCB 工程设置
    [stm32f103.kicad_pcb, stm32f103.kicad_sch]
2023-01-10 Update RRADME
    [elecal_bom.xlsx, elecal_box_v1.0.stl, elecal_bracket_v1.0.stl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]
2023-02-09 更新 README 以及文件命名
    [box_v2.0.step, bracket_v2.0.step, button1_v2.0.step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]
2023-02-23 修改 PCB 库文件
    [bom.xlsx, edge_cuts.dxf, stm32f103.kicad_pcb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]
2023-02-23 修改文件组织目录
    [bom.xlsx, box_v2.0.step, bracket_v2.0.step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]
2023-02-25 更新封装库
    [stm32f103.kicad_pcb, stm32f103.kicad_sch]
2023-02-26 转换符号库文件格式
2023-03-24 Update ina226_i2c.c
    防止编译器优化重要变量
2023-08-17 软件架构调整
2023-08-18 删除中间文件
2023-08-18 目录调整
2023-08-24 框架更新
2023-08-26 修复 NT Action 事件有效位消失问题
    [key.c, led.c, main.c]
2023-08-26 增加卡尔曼滤波
2023-08-27 更新任务管理器
2023-08-27 移除不必要的字体
2023-10-10 修改开关逻辑方式
2023-10-19 修改数据桥接框架
2023-12-15 修改页面调度器，让调度器更加模块化
2023-12-15 修改文件的分类/组织
2025-08-26 重组工程目录便于理解
